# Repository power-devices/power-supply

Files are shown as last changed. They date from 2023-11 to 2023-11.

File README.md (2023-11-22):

# Welcome to the Power Supply electronics repository

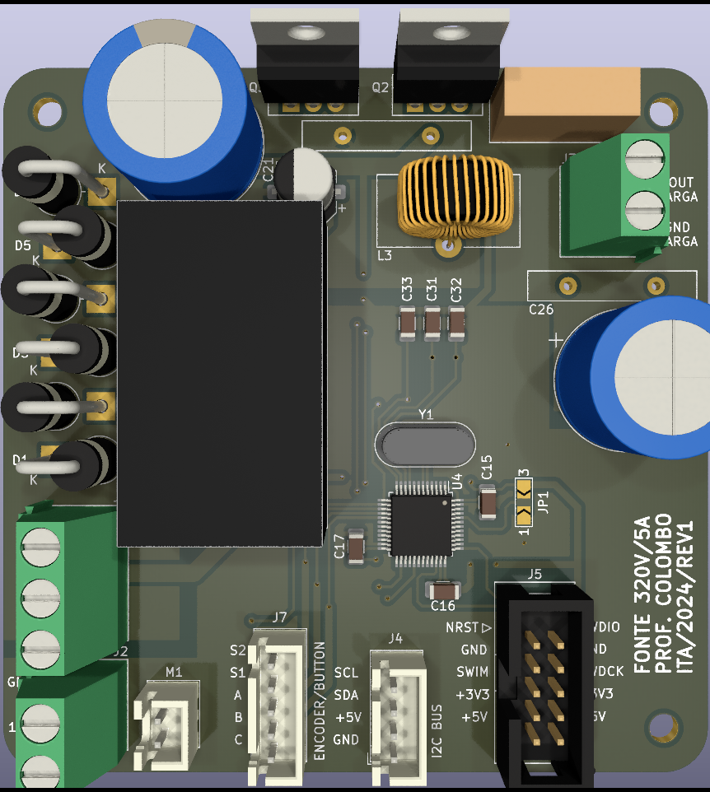
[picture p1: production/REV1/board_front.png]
REV1 board front 3D model

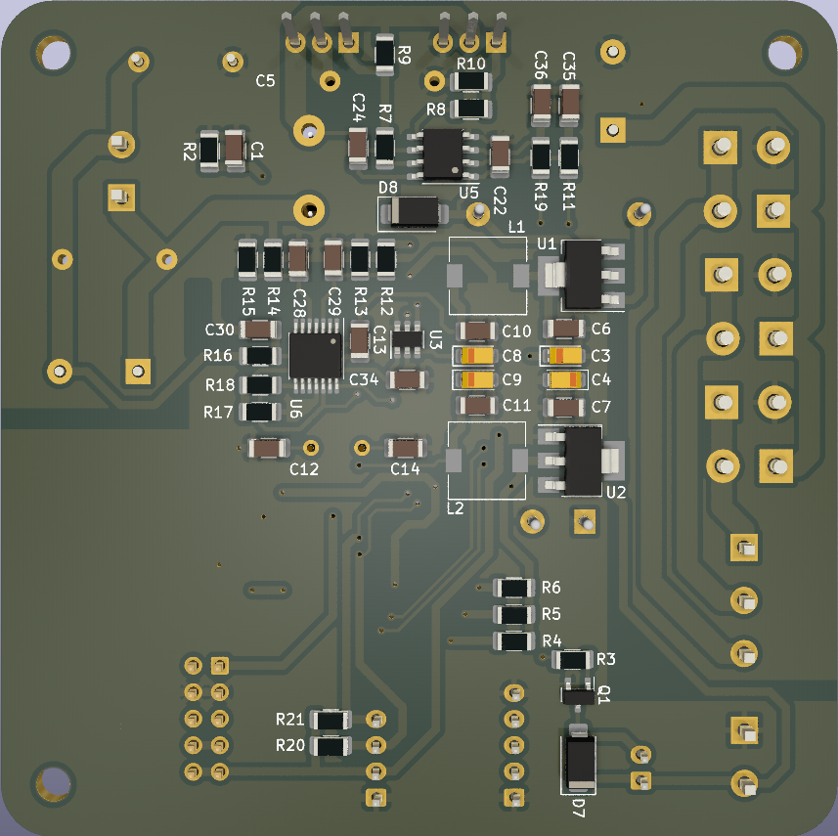
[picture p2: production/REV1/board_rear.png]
REV1 board rear 3D model

I teach power electronics and I want to provide my students the best experience possible. This is the reason I created this project. I intend to allow people to produce power electronics devices at an extreme low cost. This board required only 2 layers, but this is no problem today due to [JLCPCB](https://jlcpcb.com/) or other manufacturers.

So far, the project is divided into 3 pieces:

 1. Power supply: used to delivery power the other boards, it is compatible with mono-three phase up to 220 VAC
 2. Power bullet: a three phase h-bridge, simple as that
 3. Power brain F103: the main controller

# Disclaimer

I provide no warranty at all. Use it at your own risk!

# What will I find here?

You will find the design and production files. To edit the schematic/board you will need to install Kicad. I used version 7 to create this board.

# What can I do with this?

In this repository the board design and production files are stored. You are welcome to download/distribute it, use it, whatever.

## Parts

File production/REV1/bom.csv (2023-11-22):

Designator | Footprint | Quantity | Value | LCSC Part #
C1, C10, C11, C15, C22, C24, C6, C7 | 1206 | 8 | 1uF
C12, C14 | 1206 | 2 | 22pF
C13, C16, C17 | 1206 | 3 | 100nF
C2, C27 | CP_Radial_D16.0mm_P7.50mm | 2 | 47uF
C21 | CP_Elec_6.3x7.7 | 1 | 100uF
C26, C5 | C_Disc_D19.0mm_W3.0mm_P10.00mm | 2 | 100nF
C28, C29 | 1206 | 2 | 2n2
C3, C4, C8, C9 | CP_EIA-3216-18_Kemet-A | 4 | 10uF
C30 | 1206 | 1 | 3n3
C31, C32, C33, C34 | 1206 | 4 | 10nF
C35, C36 | 1206 | 2 | 33nF
D1, D2, D3, D4, D5, D6 | D_DO-201AD_P5.08mm_Vertical_KathodeUp | 6 | 1N5408
D7 | D_SMA | 1 | SS14
D8 | D_SMA | 1 | 1N4007
J1 | TerminalBlock_Phoenix_MKDS-1,5-3-5.08_1x03_P5.08mm_Horizontal | 1 | Screw_Terminal_01x03
J2, J3 | TerminalBlock_Phoenix_MKDS-1,5-2-5.08_1x02_P5.08mm_Horizontal | 2 | Screw_Terminal_01x02
J4 | JST_XH_B4B-XH-A_1x04_P2.50mm_Vertical | 1 | I2C
J5 | IDC-Header_2x05_P2.54mm_Vertical | 1 | SWD
J7 | JST_XH_B5B-XH-A_1x05_P2.50mm_Vertical | 1 | ENCODER
JP1 | SolderJumper-3_P2.0mm_Open_TrianglePad1.0x1.5mm_NumberLabels | 1 | ~
L1, L2 | L_7.3x7.3_H4.5 | 2 | 100uH
L3 | L_Toroid_Vertical_L16.0mm_W8.0mm_P7.62mm | 1 | 1mH
M1 | JST_XH_B2B-XH-A_1x02_P2.50mm_Vertical | 1 | Fan
PS1 | Converter_ACDC_HiLink_HLK-PMxx | 1 | HLK-PM12
Q1 | SOT-23 | 1 | MMBT3904
Q2, Q3 | TO-220-3_Vertical | 2 | FDP11N50
R1 | R_Box_L14.0mm_W5.0mm_P9.00mm | 1 | 0R1
R10, R9 | 1206 | 2 | 10k
R11, R19 | 1206 | 2 | 100R
R12, R14 | 1206 | 2 | 180k
R13, R15 | 1206 | 2 | 1k5
R16, R3 | 1206 | 2 | 1k
R17 | 1206 | 1 | 6k8
R18 | 1206 | 1 | 33k
R2 | 1206 | 1 | 1R
R20, R21, R4, R5, R6 | 1206 | 5 | 3k3
R7, R8 | 1206 | 2 | 47R
U1 | SOT-223-3_TabPin2 | 1 | AMS1117-5.0
U2 | SOT-223-3_TabPin2 | 1 | AMS1117-3.3
U3 | SOT-23-6 | 1 | MCP4725xxx-xCH
U4 | LQFP-48_7x7mm_P0.5mm | 1 | STM32F103C8Tx
U5 | SOIC-8_3.9x4.9mm_P1.27mm | 1 | IR2101
U6 | TSSOP-14_4.4x5mm_P0.65mm | 1 | LM324
Y1 | Crystal_HC49-4H_Vertical | 1 | 16MHz

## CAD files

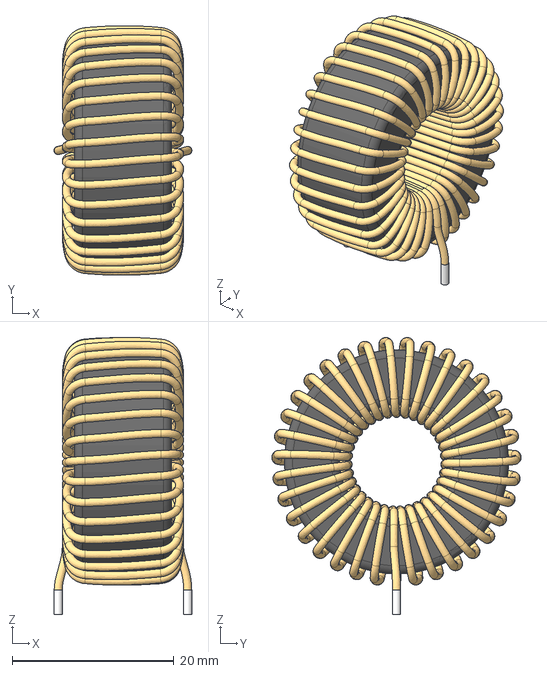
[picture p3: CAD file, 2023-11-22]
3d/Ind500uH.stp
17.0 x 30.8 x 34.2 mm

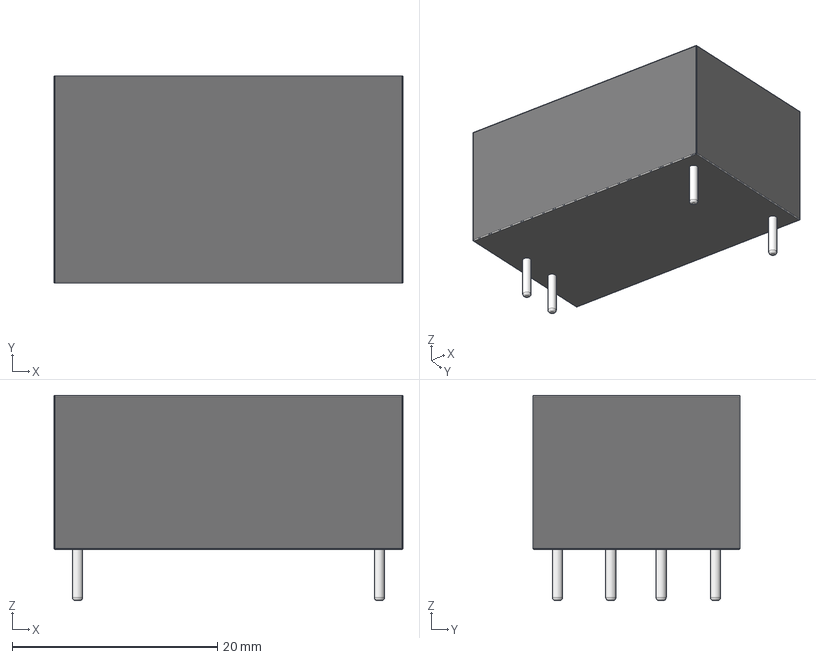
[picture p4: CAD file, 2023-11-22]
3d/hlk-pm01.step
34.0 x 20.2 x 20.0 mm

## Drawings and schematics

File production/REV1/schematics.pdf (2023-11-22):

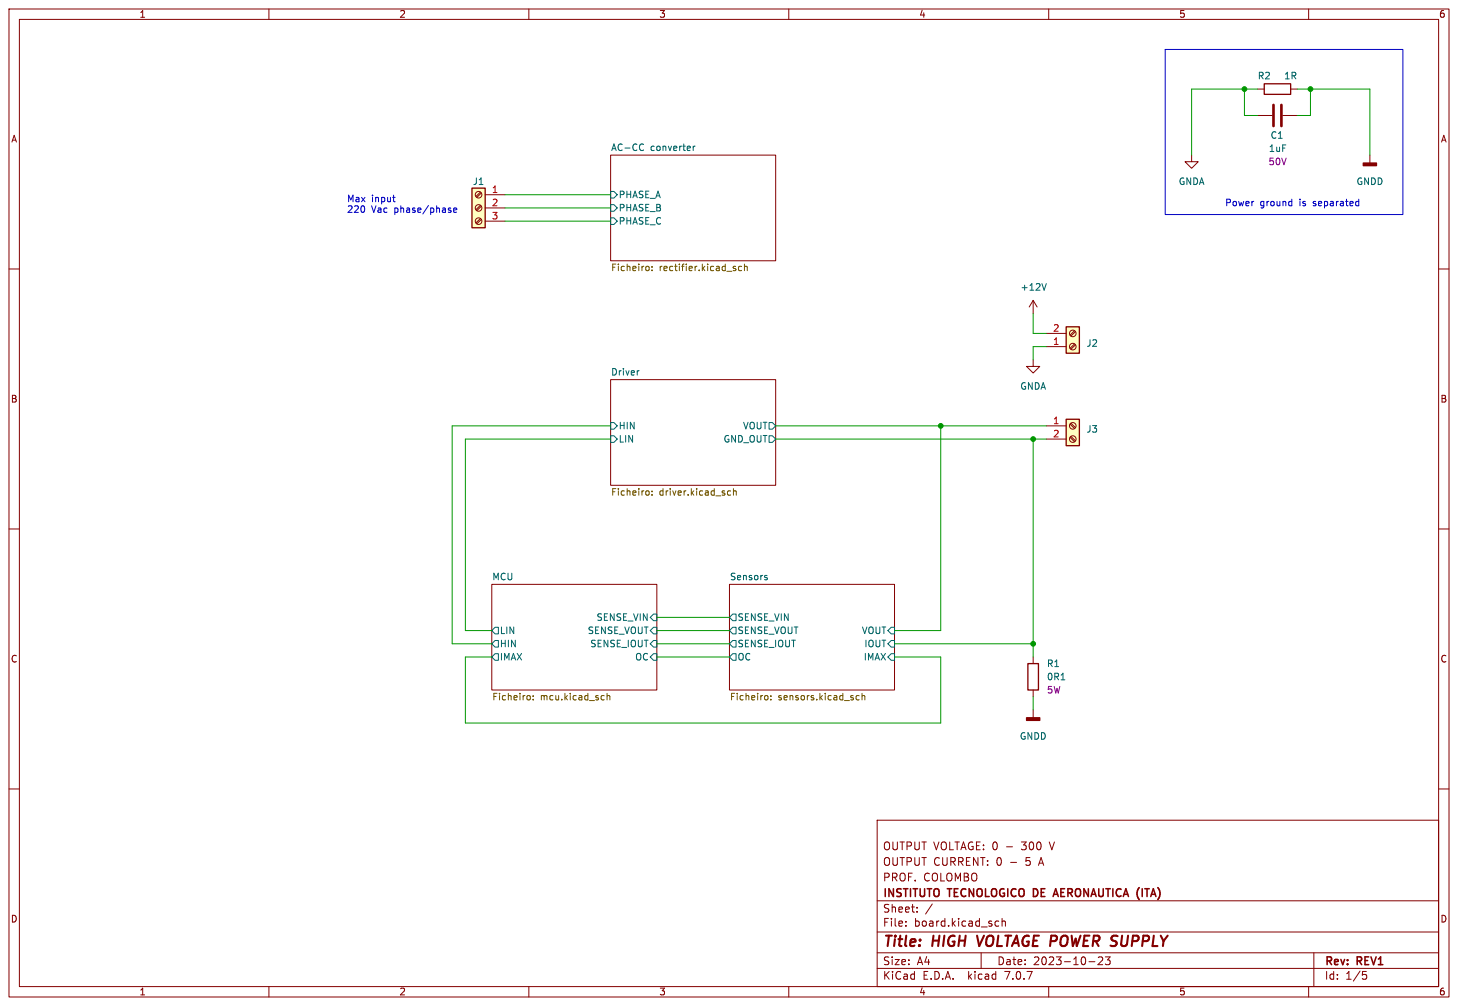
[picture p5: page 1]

Power ground is separated Max input 220 Vac phase/phase

OUTPUT CURRENT: 0 - 5 A OUTPUT VOLTAGE: 0 - 300 V

File: board.kicad_sch Sheet: /
Id: 1/5 Title: HIGH VOLTAGE POWER SUPPLY

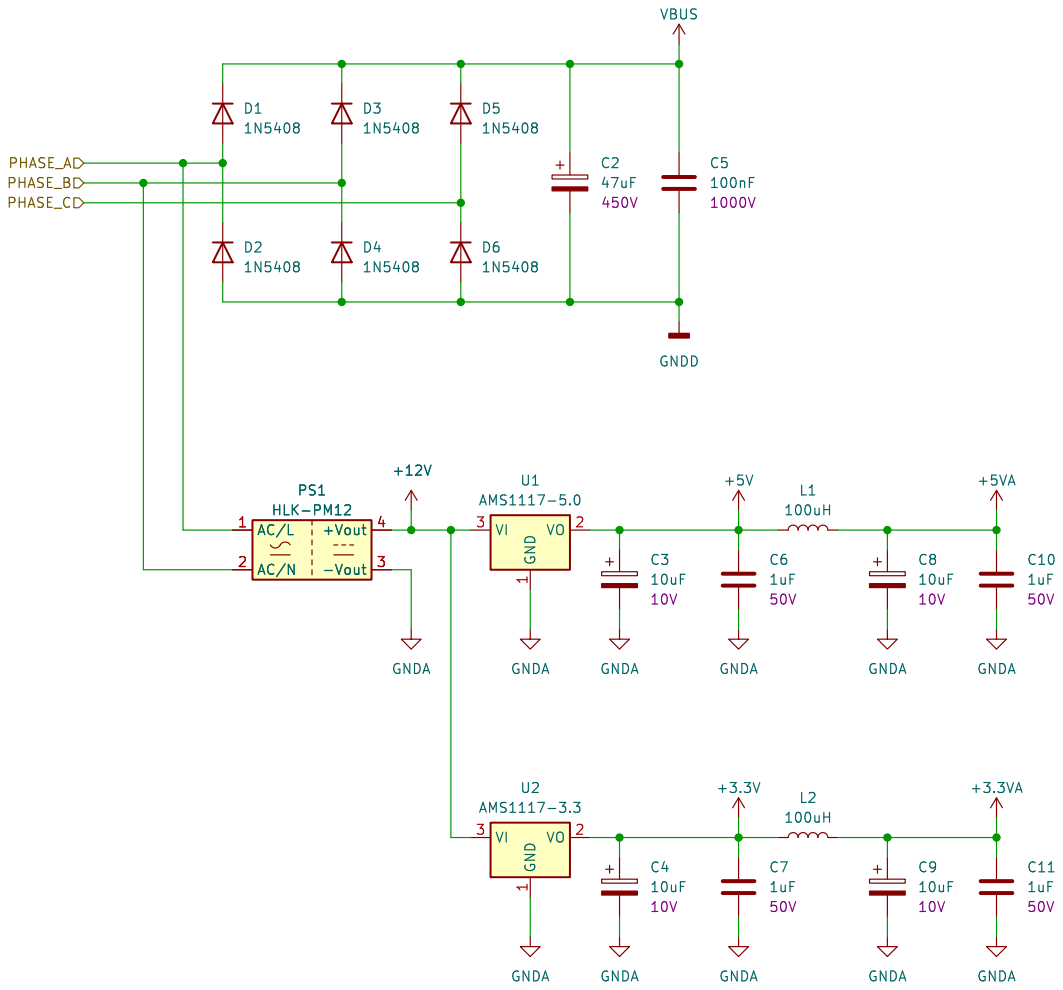
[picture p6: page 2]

1 VO 2 VI 3 U1 AMS1117-5.0 GNDA GNDA C10

OUTPUT CURRENT: 0 - 5 A OUTPUT VOLTAGE: 0 - 300 V

Id: 2/5 Title: HIGH VOLTAGE POWER SUPPLY

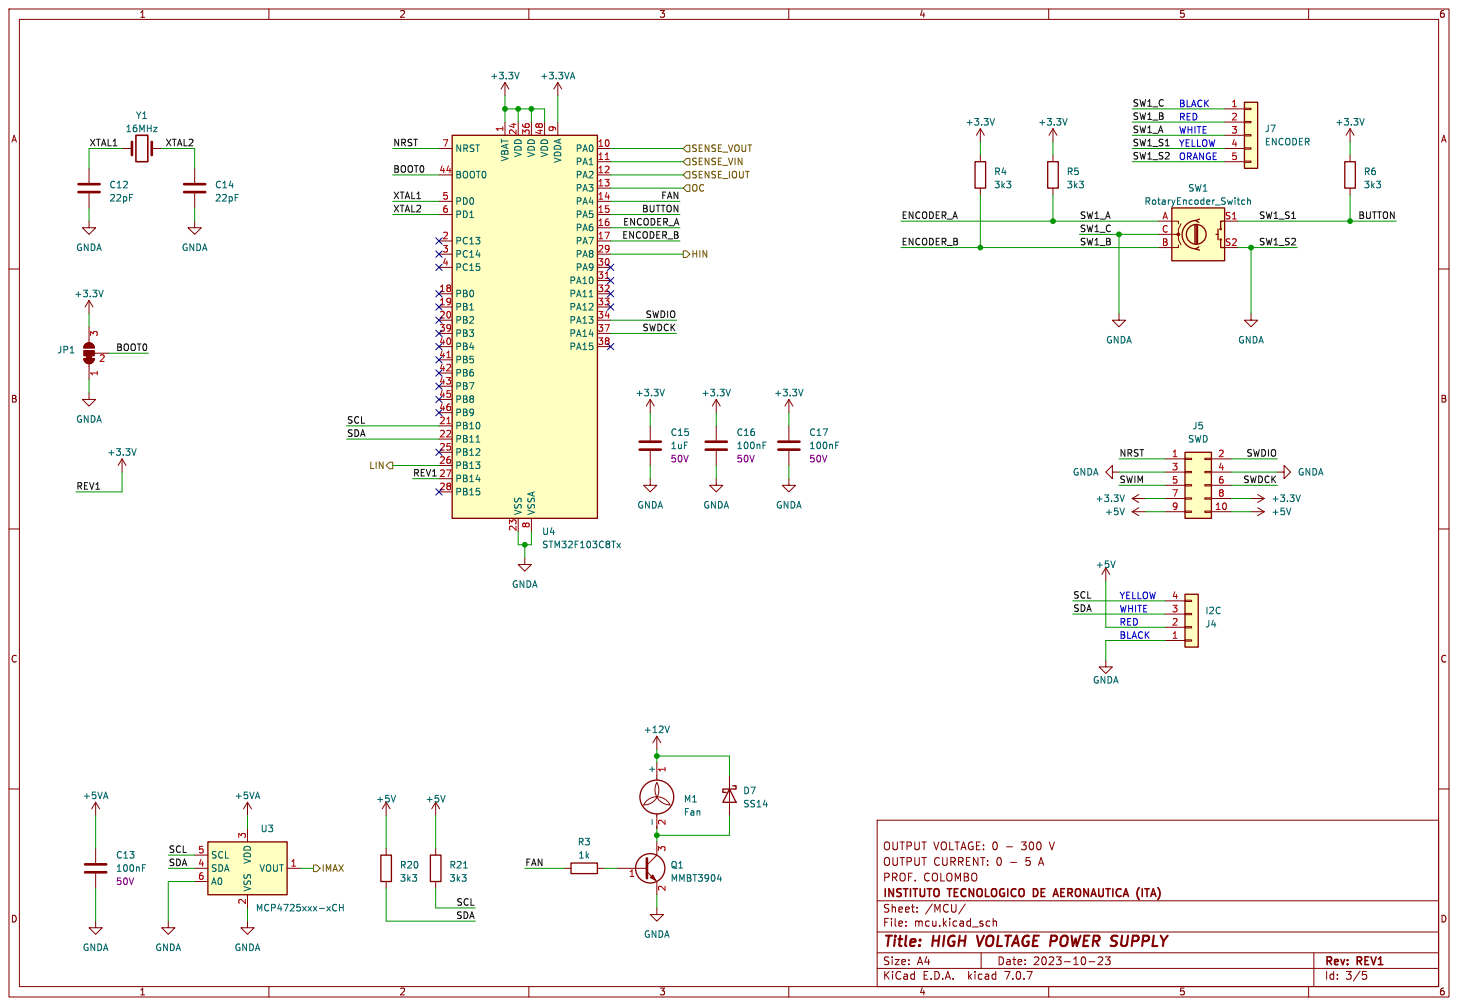
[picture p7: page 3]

1 PA0 10 PA1 11 PA2 12 PA3 13 PA4 14 PA5 15 PA6 16 PA7 17 PB0 18 PB1 19 PC13 2 PB2 20 PB10 21 PB11 22 VSS 23 VDD 24 PB12 25 PB13 26 PB14 27 PB15 28 PA8 29 PC14 3 PA9 30 PA10 31 PA11 32 PA12 33 PA13 34 VDD 36 PA14 37 PA15 38 PB3 39 PC15 4 PB4 40 PB5 41 PB6 42 PB7 43 BOOT0 44 PB8 45 PB9 46 VDD 48 PD0 5 PD1 6 NRST 7 VSSA

3 SDA 4 SCL 5 A0 6 U3 MCP4725xxx-xCH GNDA

OUTPUT CURRENT: 0 - 5 A OUTPUT VOLTAGE: 0 - 300 V

File: mcu.kicad_sch Sheet: /MCU/
Id: 3/5 Title: HIGH VOLTAGE POWER SUPPLY

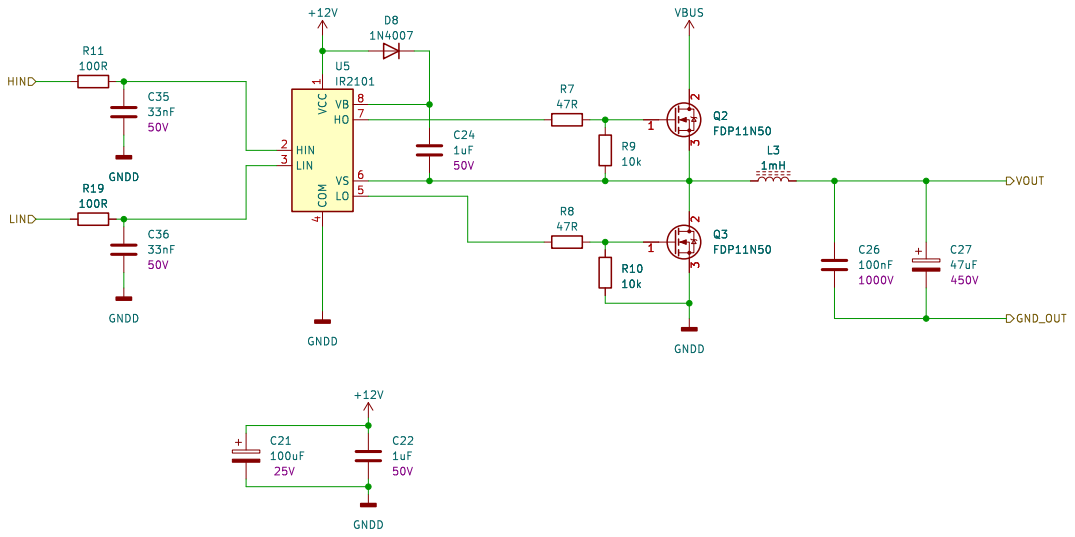
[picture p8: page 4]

OUTPUT CURRENT: 0 - 5 A OUTPUT VOLTAGE: 0 - 300 V

File: driver.kicad_sch Sheet: /Driver/
Id: 4/5 Title: HIGH VOLTAGE POWER SUPPLY

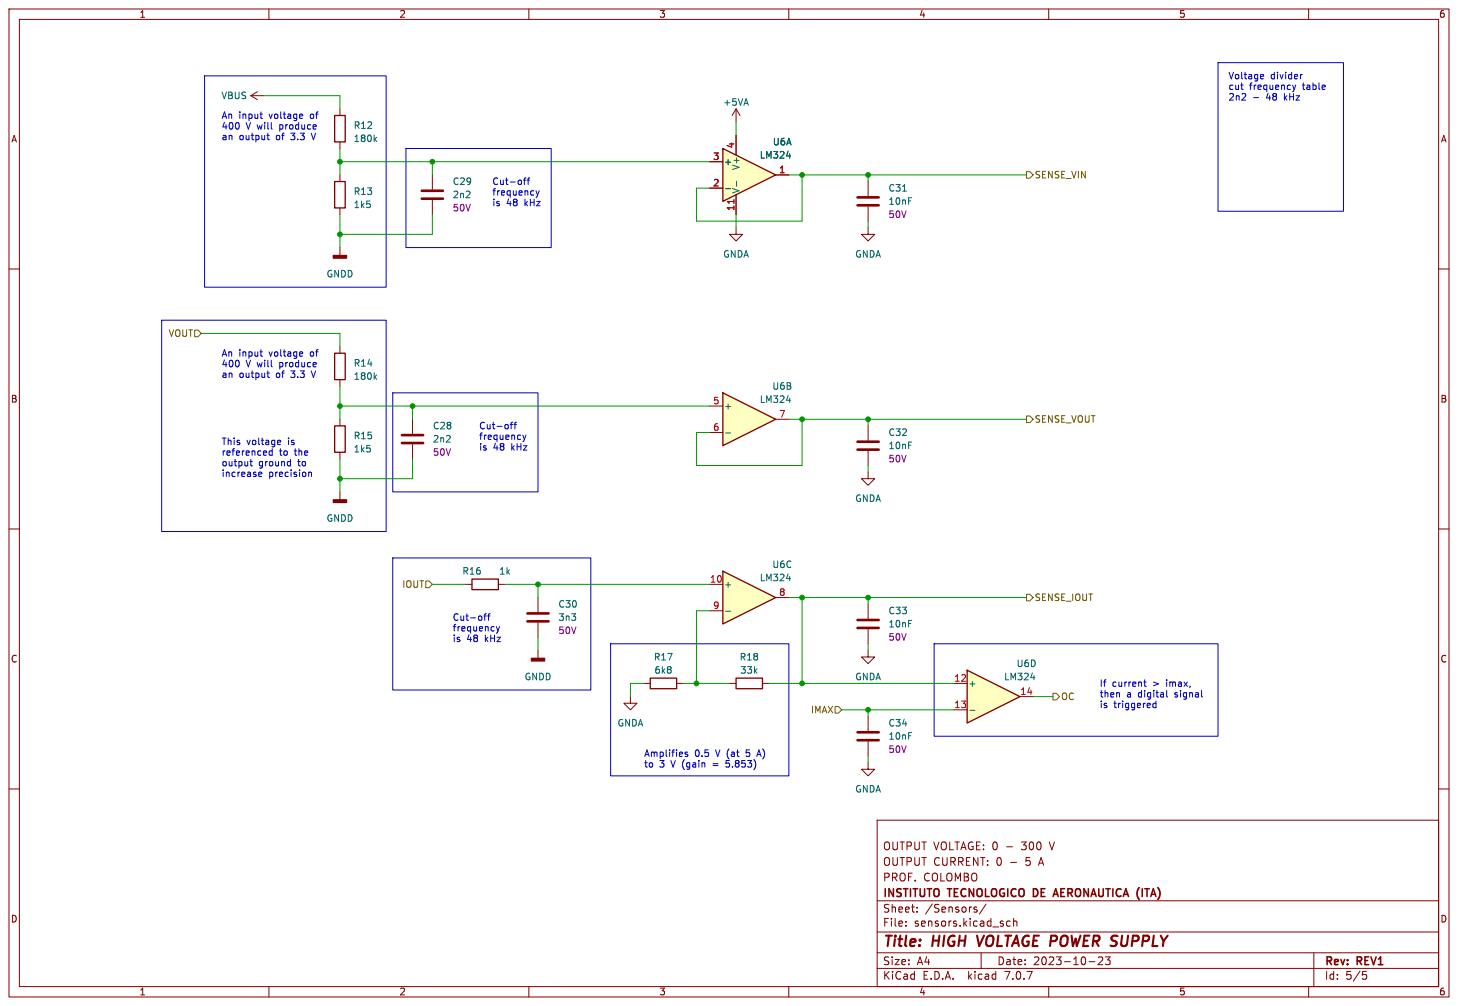
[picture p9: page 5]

An input voltage of 400 V will produce
is 48 kHz Cut-off

increase precision An input voltage of 400 V will produce

OUTPUT CURRENT: 0 - 5 A OUTPUT VOLTAGE: 0 - 300 V

File: sensors.kicad_sch Sheet: /Sensors/
Id: 5/5 Title: HIGH VOLTAGE POWER SUPPLY

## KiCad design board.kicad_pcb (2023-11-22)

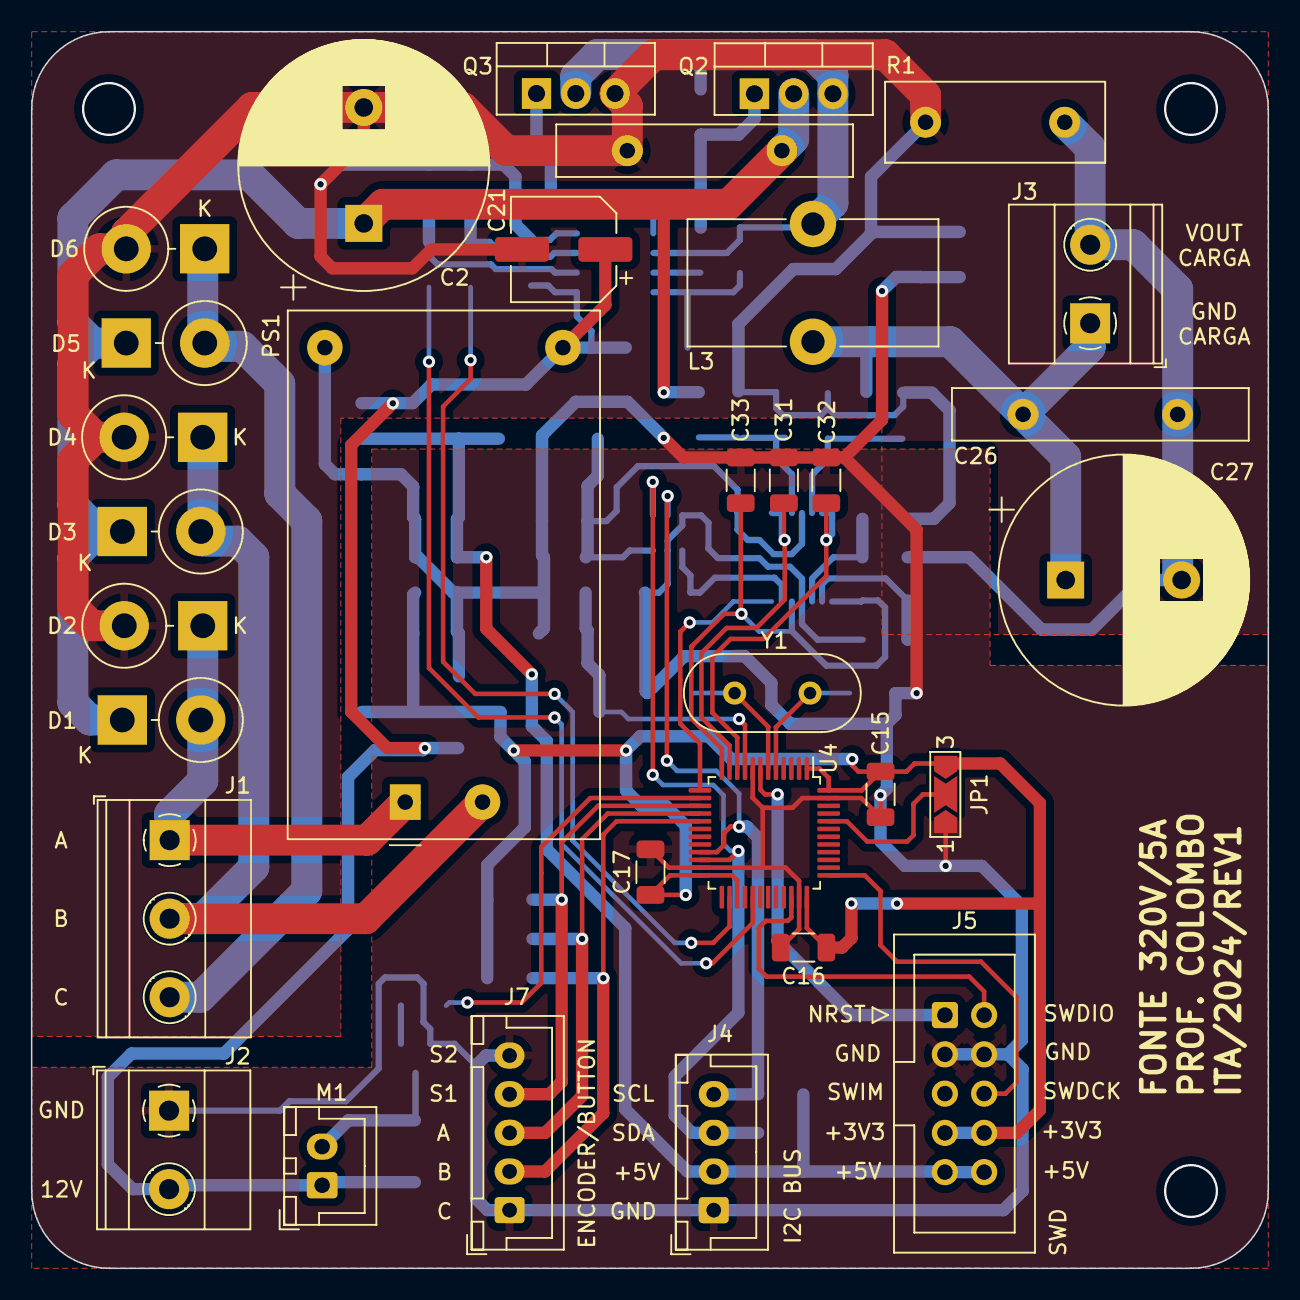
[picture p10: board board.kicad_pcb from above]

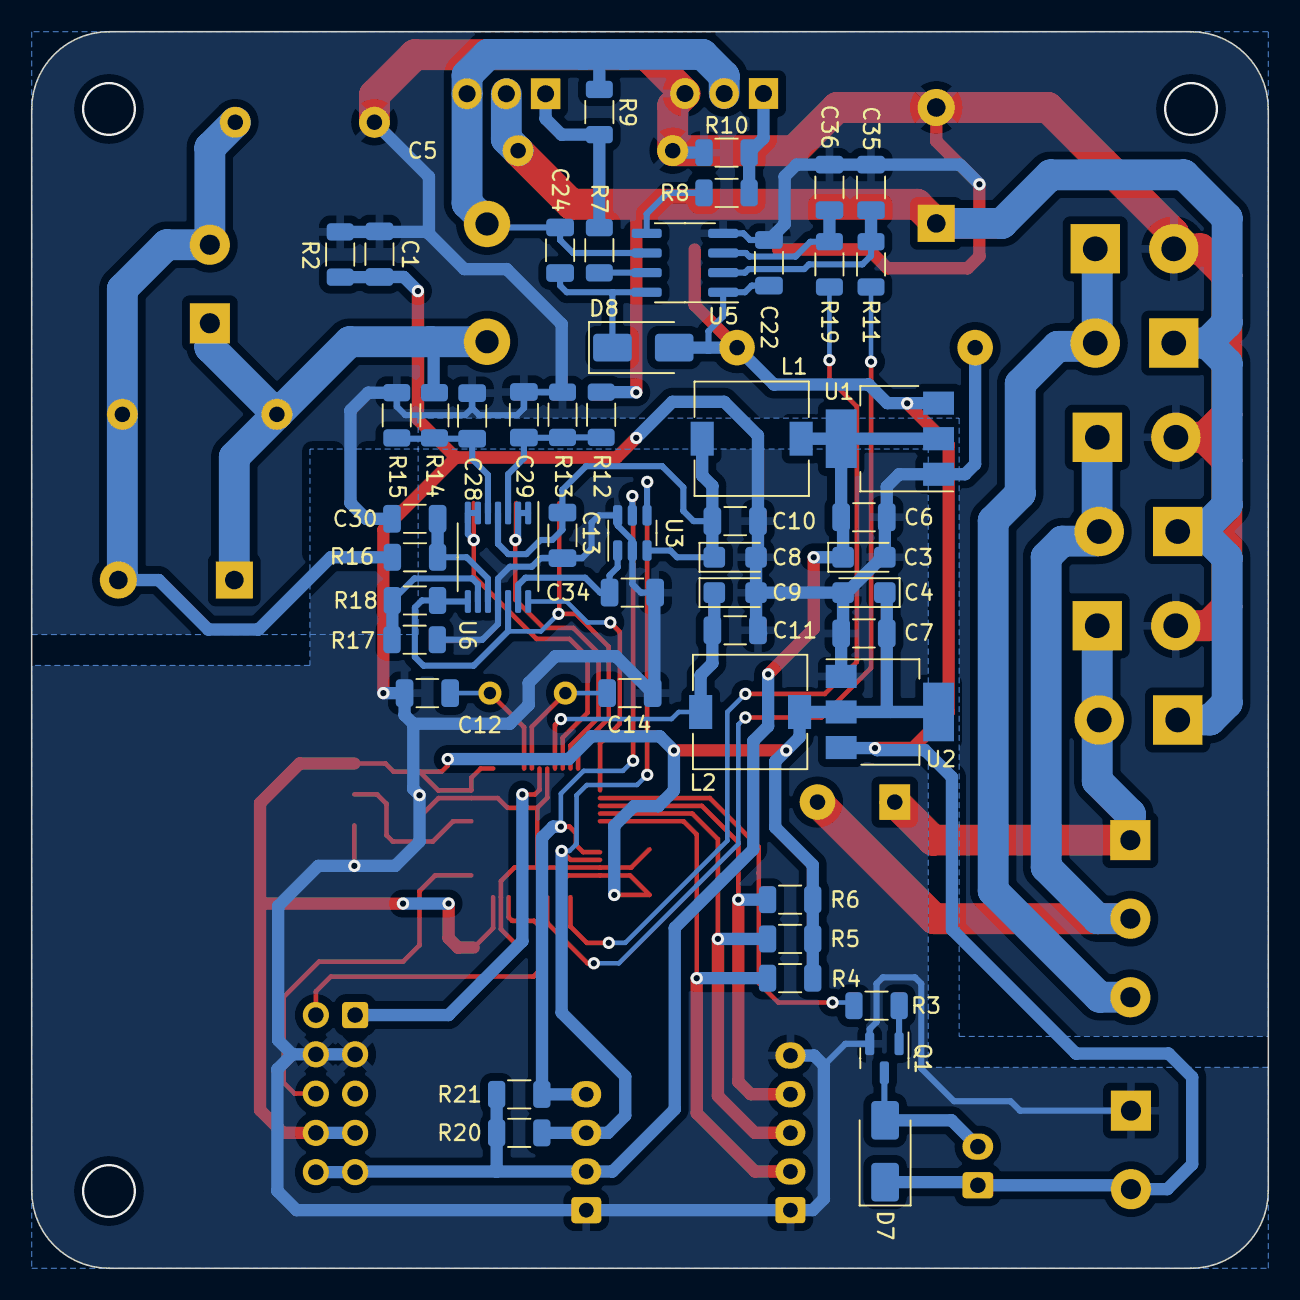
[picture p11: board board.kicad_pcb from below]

Board: 2 copper layers, 80.0 x 80.0 mm, 82 parts (50 on the bottom side), 46 nets.

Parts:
C1, C6, C7, C10, C11, C15, C22, C24: 1uF; C_1206_3216Metric
C2, C27: 47uF; CP_Radial_D16.0mm_P7.50mm
C3, C4, C8, C9: 10uF; CP_EIA-3216-18_Kemet-A
C5, C26: 100nF; C_Disc_D19.0mm_W3.0mm_P10.00mm
C12, C14: 22pF; C_1206_3216Metric
C13, C16, C17: 100nF; C_1206_3216Metric
C21: 100uF; CP_Elec_6.3x7.7
C28, C29: 2n2; C_1206_3216Metric
C30: 3n3; C_1206_3216Metric
C31, C32, C33, C34: 10nF; C_1206_3216Metric
C35, C36: 33nF; C_1206_3216Metric
D1, D2, D3, D4, D5, D6: 1N5408; D_DO-201AD_P5.08mm_Vertical_KathodeUp
D7: SS14; D_SMA
D8: 1N4007; D_SMA
J1: Screw_Terminal_01x03; TerminalBlock_Phoenix_MKDS-1,5-3-5.08_1x03_P5.08mm_Horizont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
J2, J3: Screw_Terminal_01x02; TerminalBlock_Phoenix_MKDS-1,5-2-5.08_1x02_P5.08mm_Horizont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
J4: I2C; JST_XH_B4B-XH-A_1x04_P2.50mm_Vertical
J5: SWD; IDC-Header_2x05_P2.54mm_Vertical
J7: ENCODER; JST_XH_B5B-XH-A_1x05_P2.50mm_Vertical
JP1: SolderJumper-3_P2.0mm_Open_TrianglePad1.0x1.5mm_NumberLabels
L1, L2: 100uH; L_7.3x7.3_H4.5
L3: 1mH; L_Toroid_Vertical_L16.0mm_W8.0mm_P7.62mm
M1: Fan; JST_XH_B2B-XH-A_1x02_P2.50mm_Vertical
PS1: HLK-PM12; Converter_ACDC_HiLink_HLK-PMxx
Q1: MMBT3904; SOT-23
Q2, Q3: FDP11N50; TO-220-3_Vertical
R1: 0R1; R_Box_L14.0mm_W5.0mm_P9.00mm
R2: 1R; R_1206_3216Metric
R3, R16: 1k; R_1206_3216Metric
R4, R5, R6, R20, R21: 3k3; R_1206_3216Metric
R7, R8: 47R; R_1206_3216Metric
R9, R10: 10k; R_1206_3216Metric
R11, R19: 100R; R_1206_3216Metric
R12, R14: 180k; R_1206_3216Metric
R13, R15: 1k5; R_1206_3216Metric
R17: 6k8; R_1206_3216Metric
R18: 33k; R_1206_3216Metric
U1: AMS1117-5.0; SOT-223-3_TabPin2
U2: AMS1117-3.3; SOT-223-3_TabPin2
U3: MCP4725xxx-xCH; SOT-23-6
U4: STM32F103C8Tx; LQFP-48_7x7mm_P0.5mm
U5: IR2101; SOIC-8_3.9x4.9mm_P1.27mm
U6: LM324; TSSOP-14_4.4x5mm_P0.65mm
Y1: 16MHz; Crystal_HC49-4H_Vertical

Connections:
+3.3V: C4.1, C7.1, C15.1, C16.1, C17.1, J5.7, J5.8, JP1.3 (B), L2.1, R4.1, R5.1, R6.1, U2.2 (VO), U4.1 (VBAT), U4.24 (VDD), U4.27 (PB14), U4.36 (VDD), U4.48 (VDD)
+3.3VA: C9.1, C11.1, L2.2, U4.9 (VDDA)
+5V: C3.1, C6.1, J4.2, J5.9, J5.10, L1.1, R20.1, R21.1, U1.2 (VO)
+5VA: C8.1, C10.1, C13.1, L1.2, U3.3 (VDD), U6.4 (V+)
+12V: C21.1, C22.1, D7.1 (K), D8.2 (A), J2.2, M1.1 (+), PS1.4 (+Vout), U1.3 (VI), U2.3 (VI), U5.1 (VCC)
/AC-CC converter/PHASE_A: D1.2 (A), D2.1 (K), J1.1, PS1.1 (AC/L)
/AC-CC converter/PHASE_B: D3.2 (A), D4.1 (K), J1.2, PS1.2 (AC/N)
/AC-CC converter/PHASE_C: D5.2 (A), D6.1 (K), J1.3
/Driver/GND_OUT: C26.2, C27.2, J3.2, R1.1, R16.1
/Driver/HIN: R11.1, U4.29 (PA8)
/Driver/LIN: R19.1, U4.26 (PB13)
/Driver/VOUT: C26.1, C27.1, J3.1, L3.1, R14.1
/MCU/BOOT0: JP1.2 (C), U4.44 (BOOT0)
/MCU/BUTTON: J7.4, R6.2, U4.15 (PA5)
/MCU/ENCODER_A: J7.3, R5.2, U4.16 (PA6)
/MCU/ENCODER_B: J7.2, R4.2, U4.17 (PA7)
/MCU/FAN: R3.1, U4.14 (PA4)
/MCU/IMAX: C34.1, U3.1 (VOUT), U6.13 (-)
/MCU/NRST: J5.1, U4.7 (NRST)
/MCU/OC: U4.13 (PA3), U6.14
/MCU/SCL: J4.4, R21.2, U3.5 (SCL), U4.21 (PB10)
/MCU/SDA: J4.3, R20.2, U3.4 (SDA), U4.22 (PB11)
/MCU/SENSE_IOUT: C33.1, R18.2, U4.12 (PA2), U6.8, U6.12 (+)
/MCU/SENSE_VIN: C31.1, U4.11 (PA1), U6.1, U6.2 (-)
/MCU/SENSE_VOUT: C32.1, U4.10 (PA0), U6.6 (-), U6.7
/MCU/SWDCK: J5.6, U4.37 (PA14)
/MCU/SWDIO: J5.2, U4.34 (PA13)
/MCU/XTAL1: C12.1, U4.5 (PD0), Y1.1
/MCU/XTAL2: C14.1, U4.6 (PD1), Y1.2
GNDA: C1.1, C3.2, C4.2, C6.2, C7.2, C8.2, C9.2, C10.2, C11.2, C12.2, C13.2, C14.2, C15.2, C16.2, C17.2, C31.2, C32.2, C33.2, C34.2, J2.1, J4.1, J5.3, J5.4, J7.1, J7.5, JP1.1 (A), PS1.3 (-Vout), Q1.2 (E), R2.1, R17.1, U1.1 (GND), U2.1 (GND), U3.2 (VSS), U3.6 (A0), U4.8 (VSSA), U4.23 (VSS), U4.35 (VSS), U4.47 (VSS), U6.11 (V-)
GNDD: C1.2, C2.2, C5.2, C21.2, C22.2, C28.2, C29.2, C30.2, C35.2, C36.2, D2.2 (A), D4.2 (A), D6.2 (A), Q3.3 (S), R1.2, R2.2, R10.2, R13.2, R15.2, U5.4 (COM)
unnamed: D7.2 (A), M1.2 (-), Q1.3 (C)
unnamed: C24.1, D8.1 (K), U5.8 (VB)
unnamed: Q1.1 (B), R3.2
unnamed: Q2.1 (G), R7.2, R9.1
unnamed: C24.2, L3.2, Q2.3 (S), Q3.2 (D), R9.2, U5.6 (VS)
unnamed: Q3.1 (G), R8.2, R10.1
unnamed: C35.1, R11.2, U5.2 (HIN)
unnamed: R7.1, U5.7 (HO)
unnamed: C36.1, R19.2, U5.3 (LIN)
unnamed: R8.1, U5.5 (LO)
unnamed: C29.1, R12.2, R13.1, U6.3 (+)
unnamed: C28.1, R14.2, R15.1, U6.5 (+)
unnamed: C30.1, R16.2, U6.10 (+)
unnamed: R17.2, R18.1, U6.9 (-)
VBUS: C2.1, C5.1, D1.1 (K), D3.1 (K), D5.1 (K), Q2.2 (D), R12.1

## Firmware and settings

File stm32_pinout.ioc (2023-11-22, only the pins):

Mcu.UserName=STM32F103C8Tx
PA0-WKUP.Signal=ADCx_IN0
PA1.Signal=ADCx_IN1
PA13.Signal=SYS_JTMS-SWDIO
PA14.Signal=SYS_JTCK-SWCLK
PA2.Signal=ADCx_IN2
PA6.Signal=S_TIM3_CH1
PA7.Signal=S_TIM3_CH2
PB10.Signal=I2C2_SCL
PB11.Signal=I2C2_SDA
PD0-OSC_IN.Signal=RCC_OSC_IN
PD1-OSC_OUT.Signal=RCC_OSC_OUT
